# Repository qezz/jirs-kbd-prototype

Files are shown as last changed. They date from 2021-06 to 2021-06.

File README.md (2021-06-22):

# Jirs Keyboard Prototype

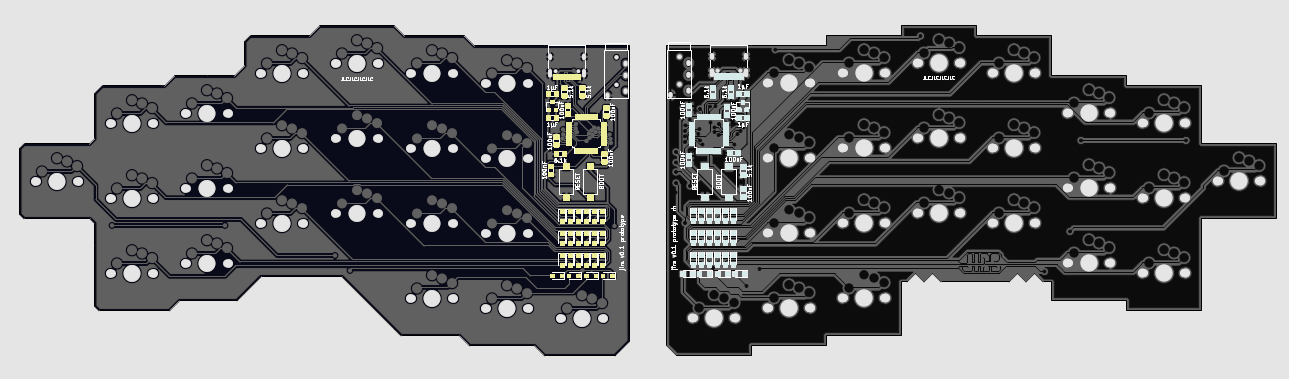
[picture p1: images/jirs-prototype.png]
Jirs


This keyboard is a fork of a great keyboard
[KeySeeBee](https://github.com/TeXitoi/keyseebee) by TeXitoi. Includes
changes to the keys layout and the components placement.

This is a prototype, so everything is a subject to change.

The firmware is [Keyberon](https://github.com/TeXitoi/keyberon)

## Planned changes

* Diodes placement: They look good on the front side of the pcb, but
  they took a lot of space. I want to move them closer to the
  switches.
* Audio Jack 3.5 mm placement looks weird to me, I used to the
  crkbd/jorne style placement, closer to the thumb cluster.
* Plated Through Holes for several features: panel cover, top plate,
  bottom plate
* I want to make several version of the keyboard. One should be slim
  (pcb only, low profile switches), another one is more common, with
  the bottom plate, top plate, panel cover. Maybe some corne-ish
  tilting. Hot-swap version for low profile and regular sockets.

## Features

* 44 keys, using Cherry MX or Kailh choc switches, only 1U keycaps;
* USB-C connector on the 2 sides;
* TRRS cable for connecting the 2 halves (for power and UART communication between the 2 halves);
* 2 STM32F072 MCU, with hardware USB DFU bootloader and crystal less USB;
* Only onboard SMD component (except for the switches and TRRS connector).

## Inspiration

* jian, jiran, and jorne for the layout
* KeySeeBee for the stm32 based pcb design

## Gallery

TBA

## Bill Of Materials

TBA

## Compiling and flashing

Install the complete toolchain and utils:

```shell
curl https://sh.rustup.rs -sSf | sh
rustup target add thumbv6m-none-eabi
rustup component add llvm-tools-preview
cargo install cargo-binutils
sudo apt-get install dfu-util
```

Compile:

```shell
cd firmware
cargo objcopy --bin jirs --release -- -O binary jirs.bin
```

To flash using dfu-util, first put the board in dfu mode by pressing
BOOT, pressing and releasing RESET and releasing BOOT. Then:

```shell
dfu-util -d 0483:df11 -a 0 -s 0x08000000:leave -D jirs.bin
```

The fist time, if the write fail, your flash might be protected. To
unprotect:

```shell
dfu-util -d 0483:df11 -a 0 -s 0x08000000:force:unprotect -D jirs.bin
```

Ideally both sides needs to be flashed, but for changes that only affect the layout it's strictly not needed as the side connected with the USB cable will determine the layout. In fact, you can have different layouts stored on each half, meaning you can switch back and forth between two layouts by moving the USB cable between the two halves.

## What's the layout

TBD

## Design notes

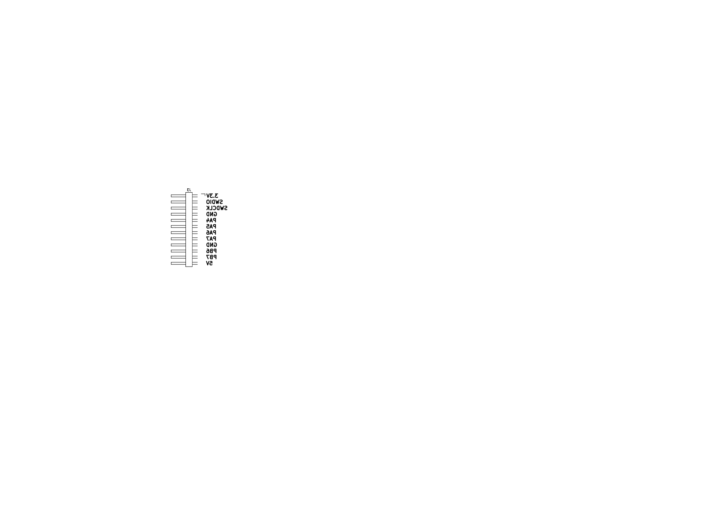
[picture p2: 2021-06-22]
pcb/gerbers/v0.1/right/right-B_SilkS.png

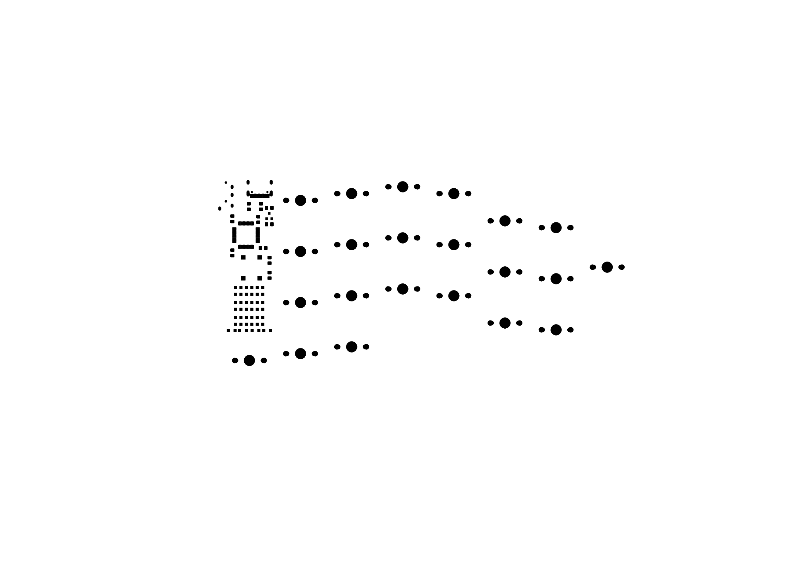
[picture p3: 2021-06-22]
pcb/gerbers/v0.1/right/right-F_Mask.png

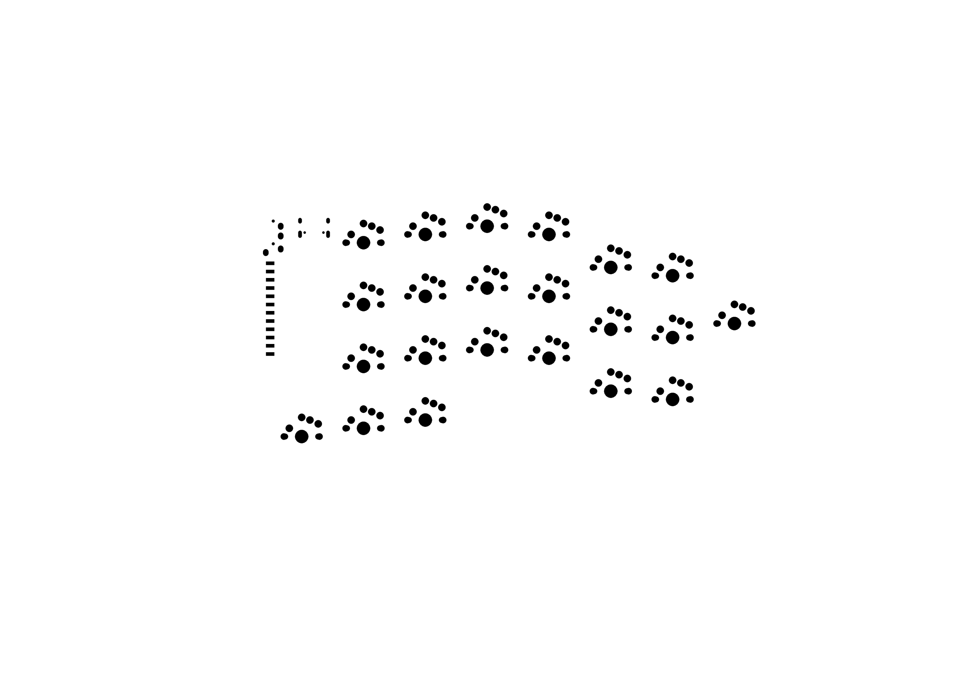
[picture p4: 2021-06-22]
pcb/gerbers/v0.1/right/right-B_Mask.png

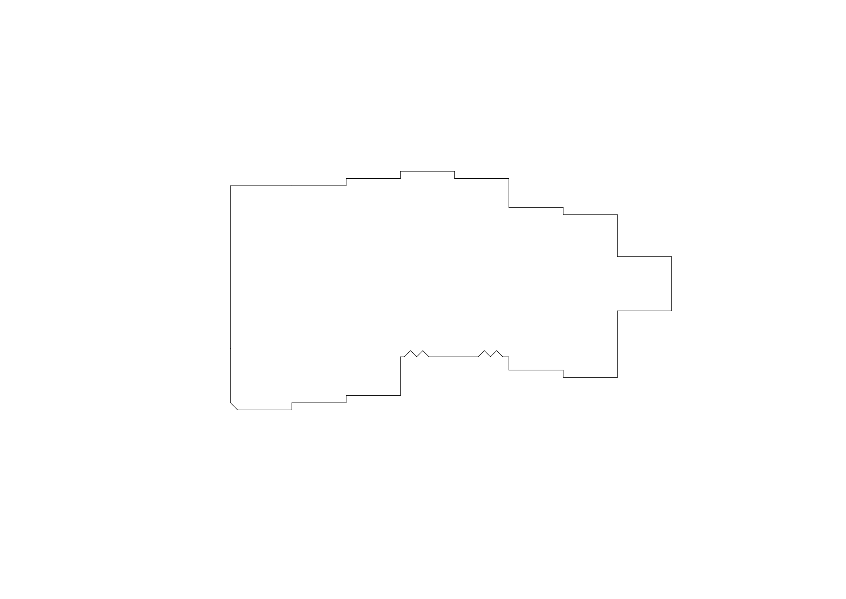
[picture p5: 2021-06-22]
pcb/gerbers/v0.1/right/right-Edge_Cuts.png

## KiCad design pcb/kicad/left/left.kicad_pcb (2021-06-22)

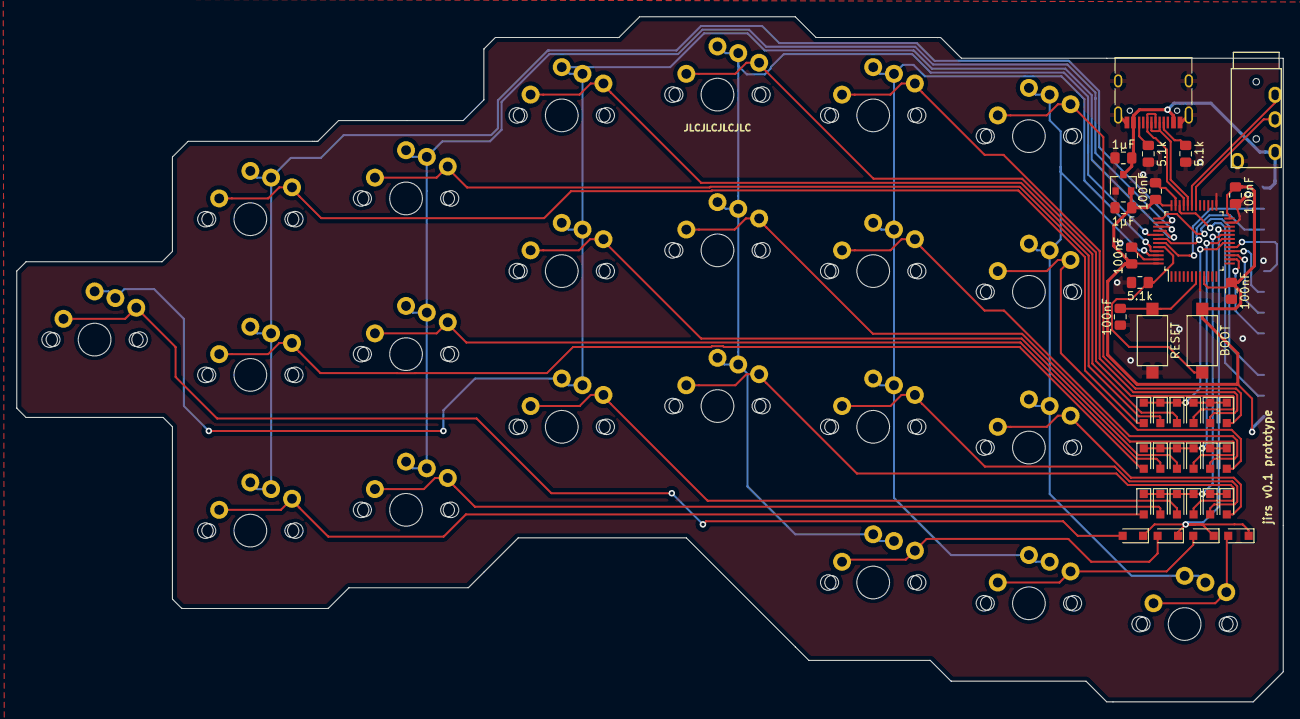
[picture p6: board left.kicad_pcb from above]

Board: 2 copper layers, 154.9 x 83.8 mm, 61 parts (1 on the bottom side), 51 nets.

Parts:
C1, C2, C3, C4, C5: 100nF; C_0805_2012Metric_Pad1.15x1.40mm_HandSolder
C6, C7: 1µF; C_0805_2012Metric_Pad1.15x1.40mm_HandSolder
D5: D1.1; D_SOD-323_HandSoldering
D6: D2.1; D_SOD-323_HandSoldering
D7: D3.1; D_SOD-323_HandSoldering
D9: D1.3; D_SOD-323_HandSoldering
D10: D2.3; D_SOD-323_HandSoldering
D11: D3.3; D_SOD-323_HandSoldering
D12: D4.3; D_SOD-323_HandSoldering
D14: D1.6; D_SOD-323_HandSoldering
D15: D2.6; D_SOD-323_HandSoldering
D16: D3.6; D_SOD-323_HandSoldering
D17: D4.6; D_SOD-323_HandSoldering
D19: D1.2; D_SOD-323_HandSoldering
D20: D2.2; D_SOD-323_HandSoldering
D21: D3.2; D_SOD-323_HandSoldering
D23: D1.4; D_SOD-323_HandSoldering
D24: D2.4; D_SOD-323_HandSoldering
D25: D3.4; D_SOD-323_HandSoldering
D26: D4.4; D_SOD-323_HandSoldering
D33: D1.5; D_SOD-323_HandSoldering
D34: D2.5; D_SOD-323_HandSoldering
D35: D3.5; D_SOD-323_HandSoldering
D36: D4.5; D_SOD-323_HandSoldering
J1: USB_C_Receptacle_USB2.0; USB_C_Receptacle_HRO_TYPE-C-31-M-12
J2: AudioJack4; TRRS-PJ-320A-no-Fmask
J3: Conn_01x12_Male; Harwin_M20-89012xx_1x12_P2.54mm_Horizontal
R1, R6, R7: 5.1k; R_0805_2012Metric_Pad1.15x1.40mm_HandSolder
SW1: BOOT; SW_SPST_CK_RS282G05A3
SW2: RESET; SW_SPST_CK_RS282G05A3
SW3, SW4, SW5, SW7, SW8, SW9, SW10, SW12, SW13, SW14, SW15, SW17, SW18, SW19, SW21, SW22, SW23, SW24, SW31, SW32, SW33, SW34: SW_Push; CherryMX_Choc_1u
U1: STM32; LQFP-48_7x7mm_P0.5mm
U2: LDO; SOT-23

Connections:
3.3V: C2.2, C3.2, C4.2, C5.2, C6.2, J3.1, SW1.2, U1.9, U1.24, U1.36, U1.48, U2.2
5V: C7.2, J1.A4, J1.A9, J1.B4, J1.B9, J2.2, J3.12, U2.3
COL1: SW3.2, SW4.2, SW5.2, U1.38
COL2: SW17.2, SW18.2, SW19.2, U1.39
COL3: SW7.2, SW8.2, SW9.2, SW10.2, U1.40
COL4: SW21.2, SW22.2, SW23.2, SW24.2, U1.41
COL5: SW31.2, SW32.2, SW33.2, SW34.2, U1.45
COL6: SW12.2, SW13.2, SW14.2, SW15.2, U1.46
D+: J1.A6, J1.B6, U1.33
D-: J1.A7, J1.B7, U1.32
GND: C1.1, C2.1, C3.1, C4.1, C5.1, C6.1, C7.1, J1.A1, J1.A12, J1.B1, J1.B12, J1.S1, J2.1, J3.4, J3.9, R1.2, R6.2, R7.2, SW2.1, U1.8, U1.23, U1.25, U1.35, U1.47, U2.1
unnamed: C1.2, SW2.2, U1.7
unnamed: D5.2, SW3.1
unnamed: D6.2, SW4.1
unnamed: D7.2, SW5.1
unnamed: D9.2, SW7.1
unnamed: D10.2, SW8.1
unnamed: D11.2, SW9.1
unnamed: D12.2, SW10.1
unnamed: D14.2, SW12.1
unnamed: D15.2, SW13.1
unnamed: D16.2, SW14.1
unnamed: D17.2, SW15.1
unnamed: D19.2, SW17.1
unnamed: D20.2, SW18.1
unnamed: D21.2, SW19.1
unnamed: D23.2, SW21.1
unnamed: D24.2, SW22.1
unnamed: D25.2, SW23.1
unnamed: D26.2, SW24.1
unnamed: D33.2, SW31.1
unnamed: D34.2, SW32.1
unnamed: D35.2, SW33.1
unnamed: D36.2, SW34.1
unnamed: J1.A5, R7.1
unnamed: J1.B5, R6.1
unnamed: R1.1, SW1.1, U1.44
PA4: J3.5, U1.14
PA5: J3.6, U1.15
PA6: J3.7, U1.16
PA7: J3.8, U1.17
PB6: J3.10, U1.42
PB7: J3.11, U1.43
ROW1: D5.1, D9.1, D14.1, D19.1, D23.1, D33.1, U1.18
ROW2: D6.1, D10.1, D15.1, D20.1, D24.1, D34.1, U1.19
ROW3: D7.1, D11.1, D16.1, D21.1, D25.1, D35.1, U1.20
ROW4: D12.1, D17.1, D26.1, D36.1, U1.21
RX: J2.4, U1.31
SWDCLK: J3.3, U1.37
SWDIO: J3.2, U1.34
TX: J2.3, U1.30

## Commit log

2021-06-22 Re-design the layout
    [left-B.Cu.gbl, left-B.Mask.gbs, left-B.SilkS.gbo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]
2021-06-22 Describe the idea of this prototype
